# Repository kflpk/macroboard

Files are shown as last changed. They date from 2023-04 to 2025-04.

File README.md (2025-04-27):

macroboard

# Macroboard

Simple ortholinear 4x4 macro keyboard with rotary encoder.

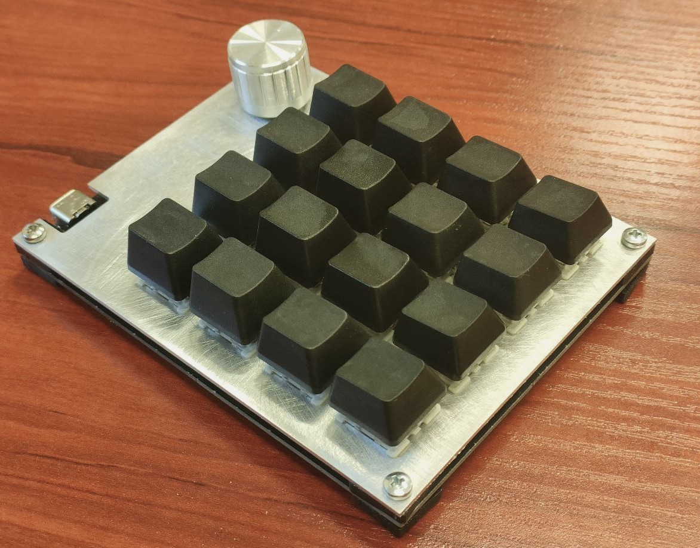
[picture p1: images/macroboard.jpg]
macroboard


## Schematics

The schematics and PCB were created using KiCAD 7. The microcontroller used is an STM32F103C6T6.

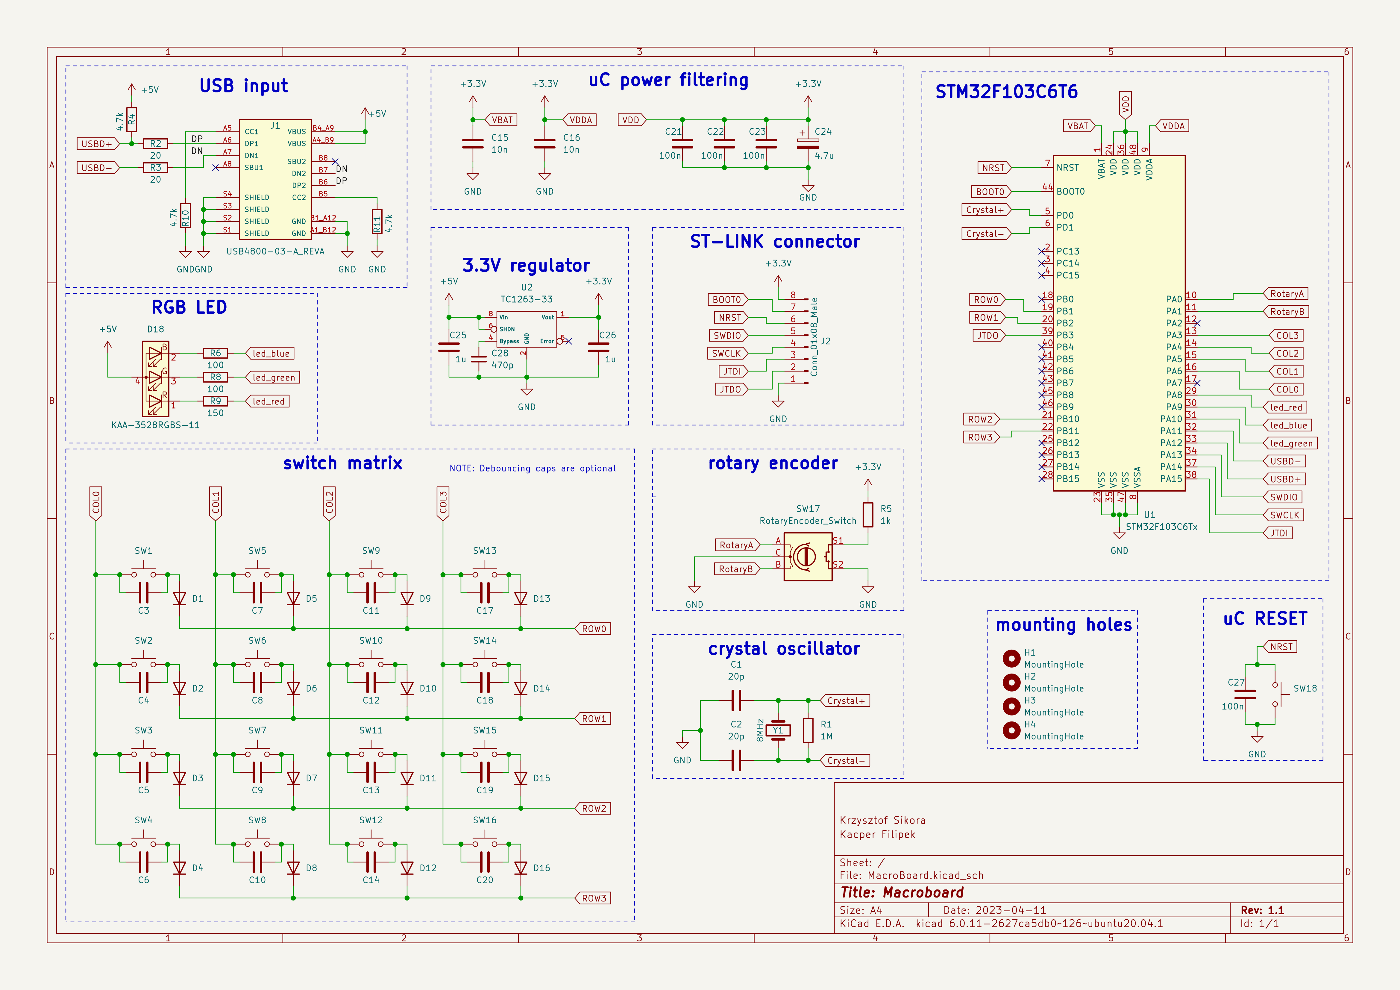
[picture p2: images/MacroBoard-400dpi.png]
schematic


## PCB
Front | Back
:-------------------------:|:-------------------------:
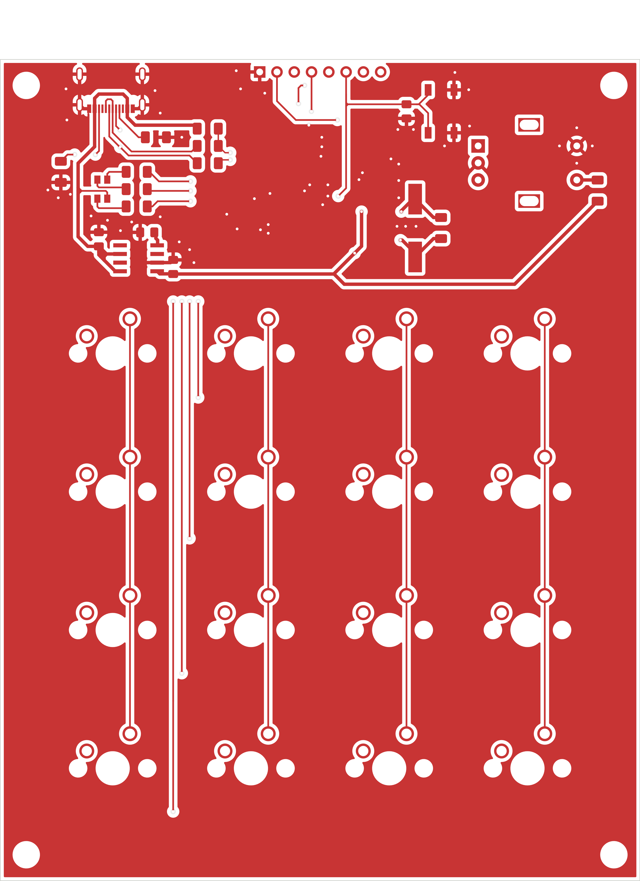
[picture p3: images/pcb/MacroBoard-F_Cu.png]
Front layer
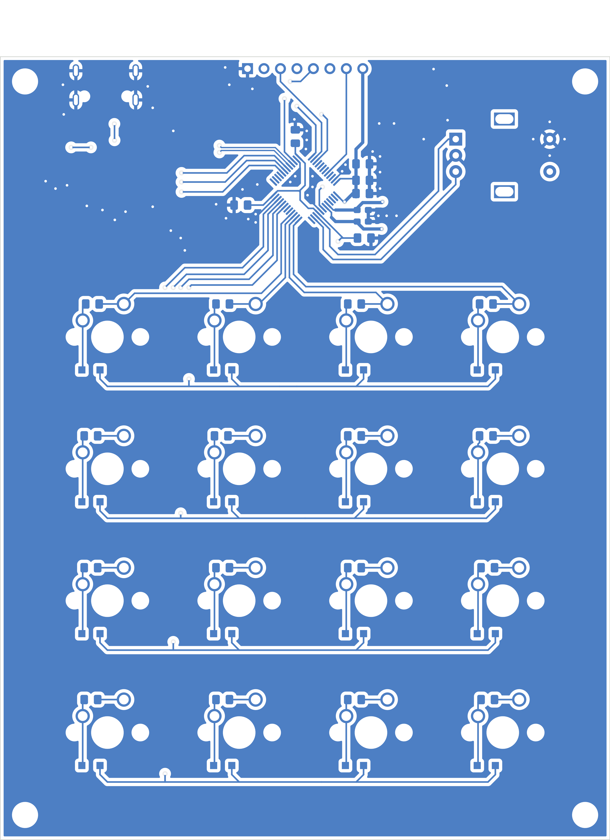
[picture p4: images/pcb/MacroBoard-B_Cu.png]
Back layer
 | 

## Mechanical parts

Mechanical design was done using Fusion 360. The front plate is a 1.5 mm thick aluminium plate, cut using a 3-axis CNC machine.
Standoffs for the board and plate were 3D printed with TPU.

You can find all the necessary files in the "mechanical" folder.

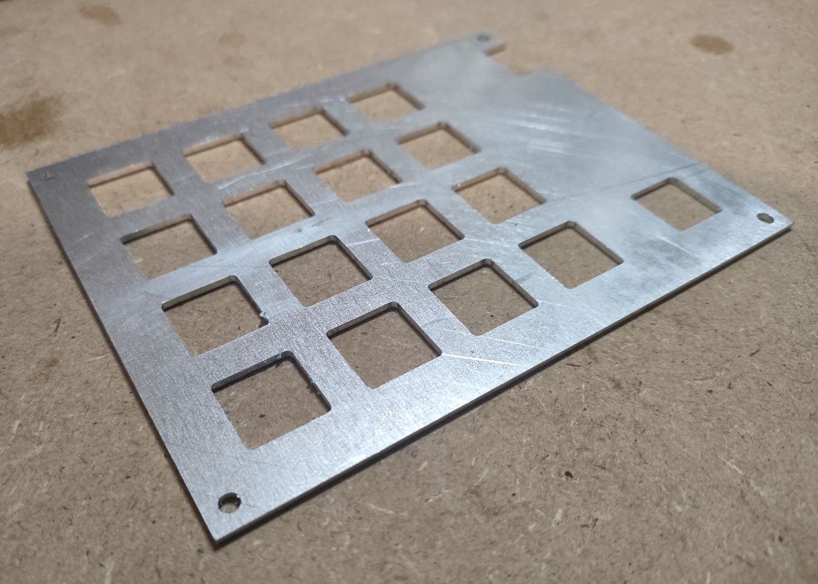
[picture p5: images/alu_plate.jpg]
alu_plate


## Dependencies
```
arm-none-eabi-binutils
arm-none-eabi-gcc
arm-none-eabi-newlib
```

## Authors
* Kacper Filipek
* Krzysztof Sikora

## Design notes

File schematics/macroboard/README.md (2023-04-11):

This folder contains the following Kicad files:
  - schematic
  - PCB design

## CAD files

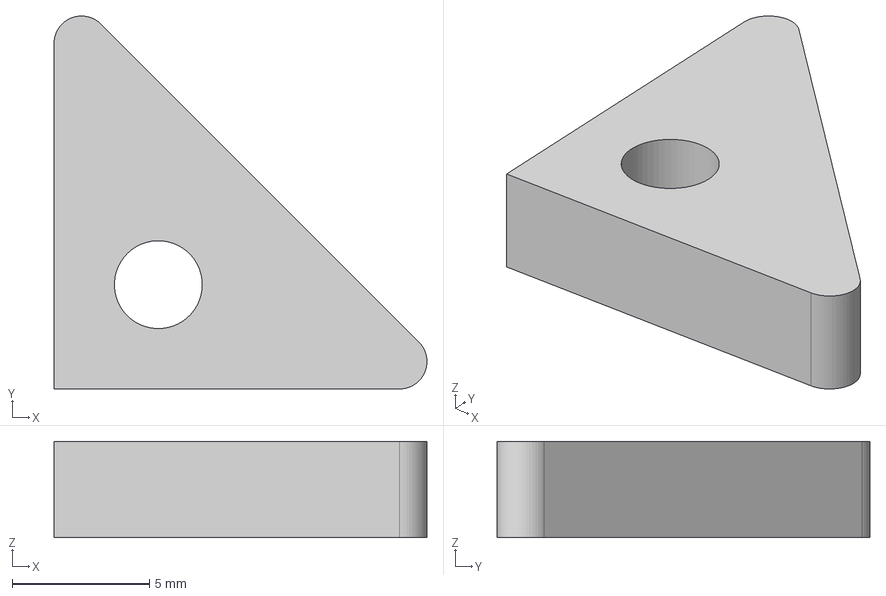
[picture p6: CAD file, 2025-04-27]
mechanical/M3 spacer.step
13.6 x 13.6 x 3.50 mm

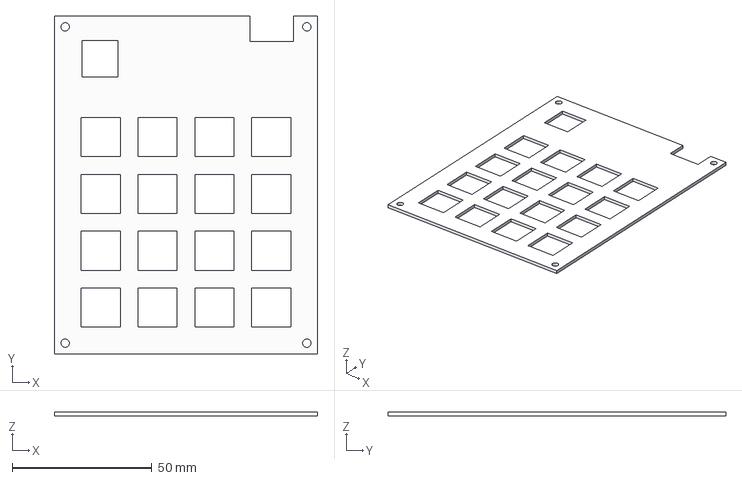
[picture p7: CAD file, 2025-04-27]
mechanical/Macroboard plate.step
94.0 x 120.7 x 1.50 mm

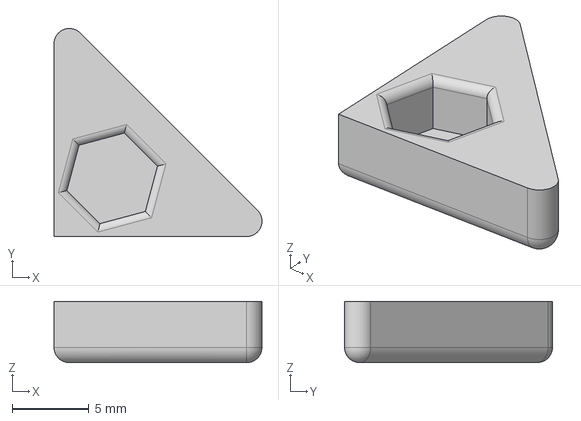
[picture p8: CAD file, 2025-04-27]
mechanical/M3 nut covers.step
13.6 x 13.6 x 4.00 mm

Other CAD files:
mechanical/M3 nut covers.f3d
mechanical/M3 spacer.f3d

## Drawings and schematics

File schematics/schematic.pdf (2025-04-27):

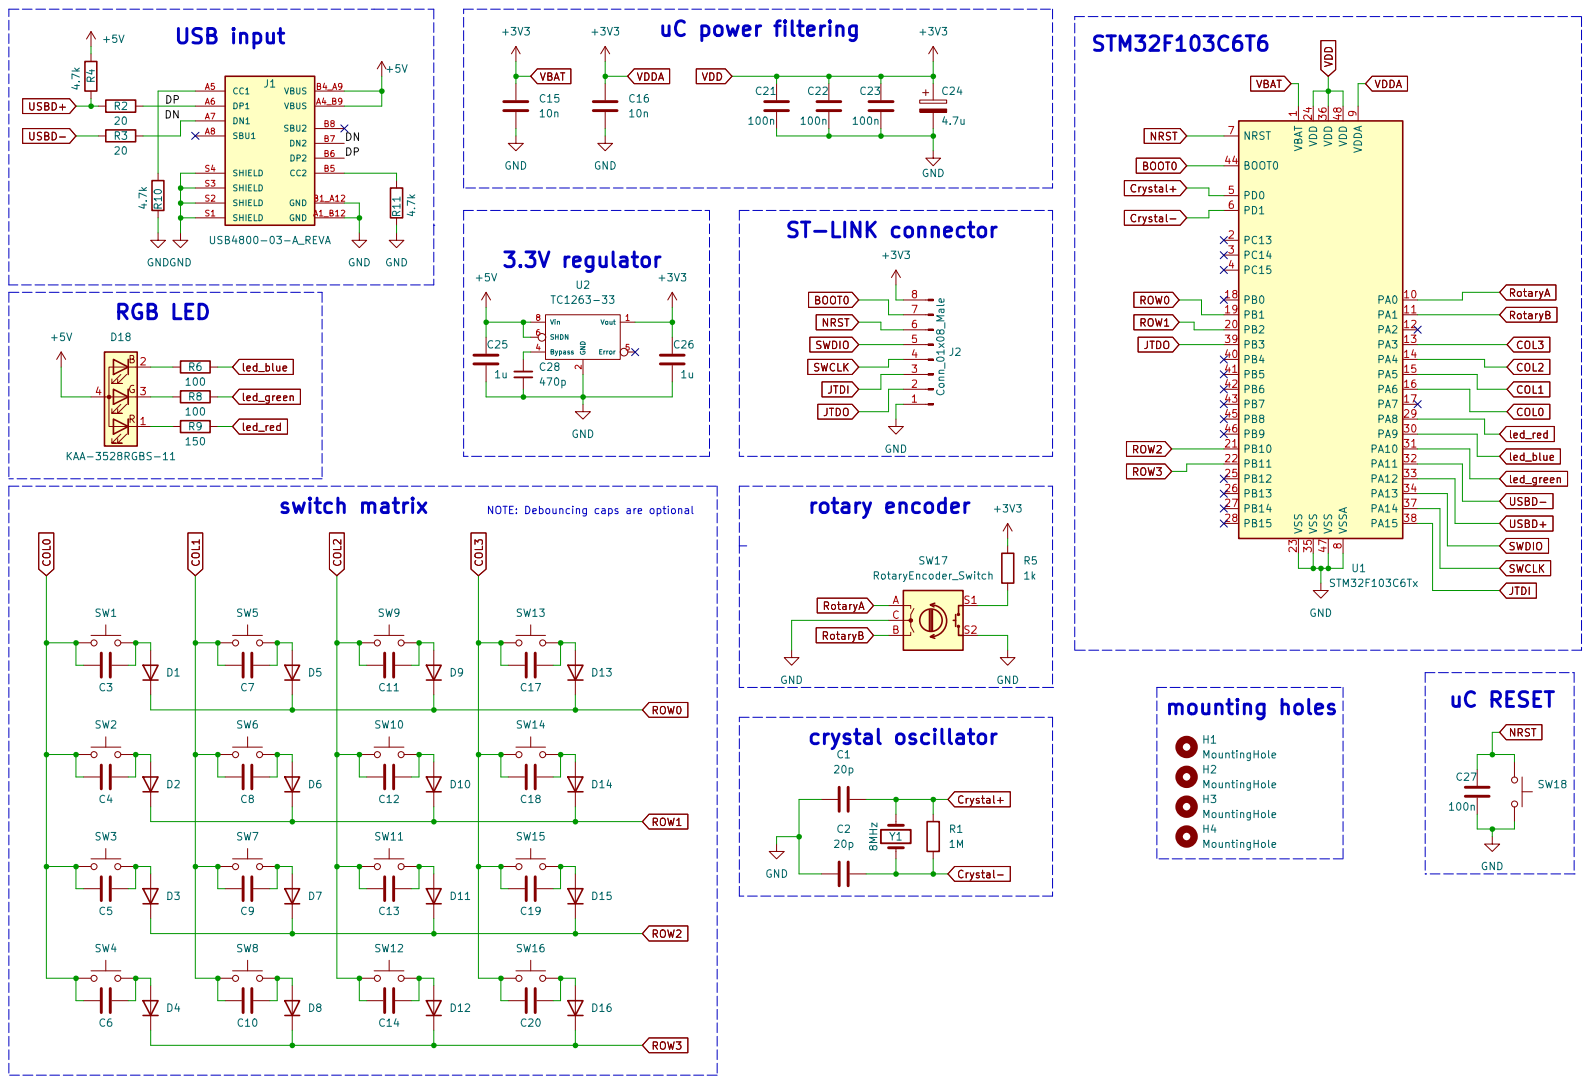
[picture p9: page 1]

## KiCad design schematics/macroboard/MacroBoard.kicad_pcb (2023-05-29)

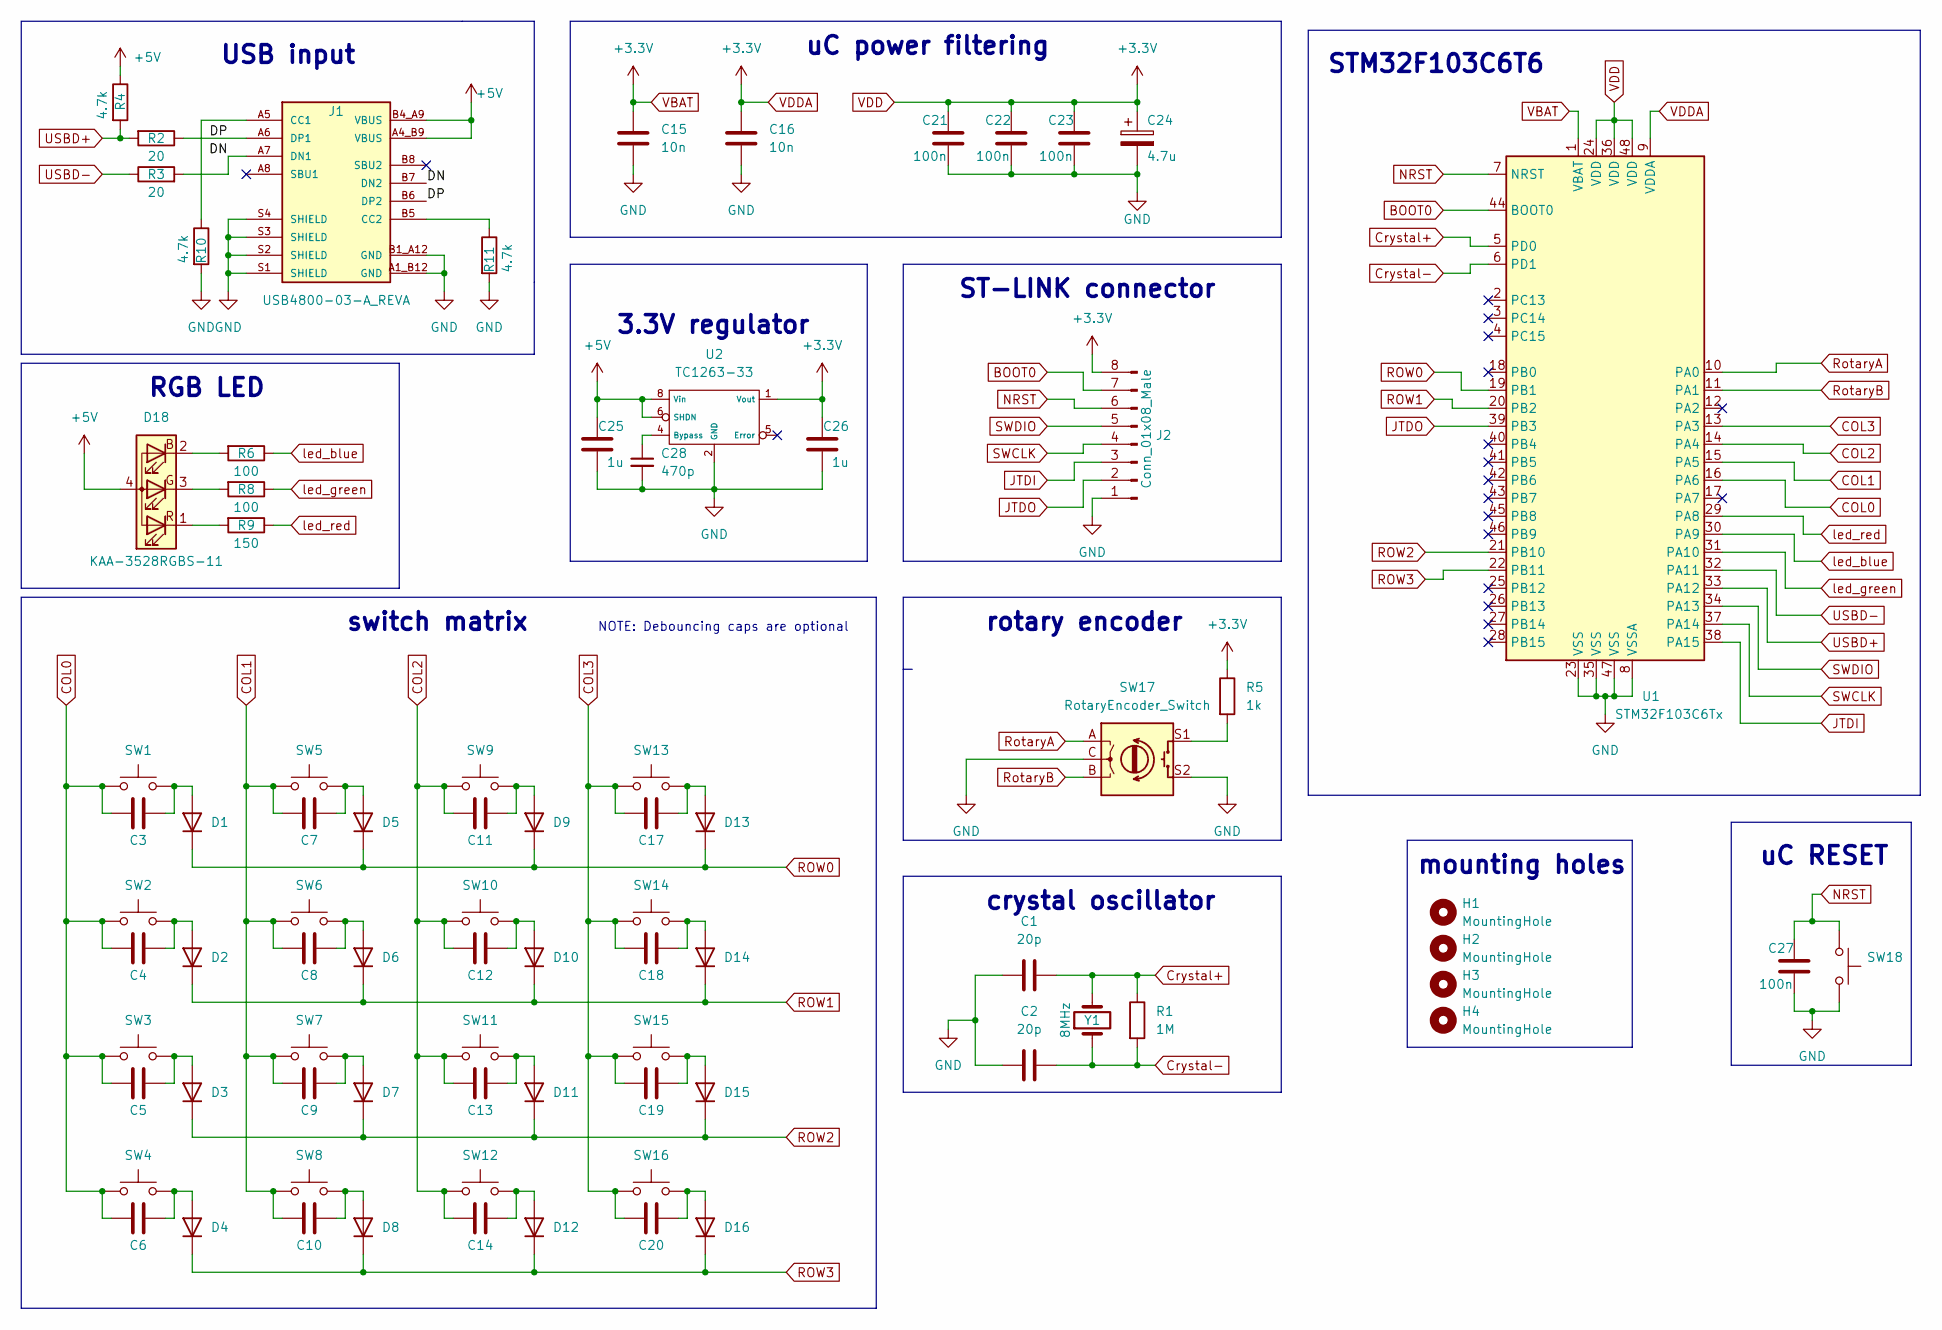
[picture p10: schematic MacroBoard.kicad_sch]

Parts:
C1, C2: 20p; C_0603_1608Metric_Pad1.08x0.95mm_HandSolder
C3, C4, C5, C6, C7, C8, C9, C10, C11, C12, C13, C14, C17, C18, C19, C20: C; C_0805_2012Metric_Pad1.18x1.45mm_HandSolder
C15, C16: 10n; C_0805_2012Metric_Pad1.18x1.45mm_HandSolder
C21, C22, C23, C27: 100n; C_0805_2012Metric_Pad1.18x1.45mm_HandSolder
C24: 4.7u; C_0805_2012Metric_Pad1.18x1.45mm_HandSolder
C25, C26: 1u; C_0805_2012Metric_Pad1.18x1.45mm_HandSolder
C28: 470p; C_0805_2012Metric_Pad1.18x1.45mm_HandSolder
D1, D2, D3, D4, D5, D6, D7, D8, D9, D10, D11, D12, D13, D14, D15, D16: D; D_SOD-123F
D18: KAA-3528RGBS-11; LED_AAA3528LSEKJ3ZGKQBKS
H1, H2, H3, H4: MountingHole; MountingHole_3mm
J1: USB4800-03-A_REVA; GCT_USB4800-03-A_REVA; PARTREV A
J2: Conn_01x08_Male; PinHeader_1x08_P2.54mm_Horizontal
R1: 1M; R_1206_3216Metric_Pad1.30x1.75mm_HandSolder
R2, R3: 20; R_1206_3216Metric_Pad1.30x1.75mm_HandSolder
R4, R10, R11: 4.7k; R_1206_3216Metric_Pad1.30x1.75mm_HandSolder
R5: 1k; R_1206_3216Metric_Pad1.30x1.75mm_HandSolder
R6, R8: 100; R_1206_3216Metric_Pad1.30x1.75mm_HandSolder
R9: 150; R_1206_3216Metric_Pad1.30x1.75mm_HandSolder
SW1, SW2, SW3, SW4, SW5, SW6, SW7, SW8, SW9, SW10, SW11, SW12, SW13, SW14, SW15, SW16: SW_Push; SW_Cherry_MX_1.00u_PCB
SW17: RotaryEncoder_Switch; RotaryEncoder_Alps_EC11E-Switch_Vertical_H20mm
SW18: SW_Push; SW_SPST_TL3342
U1: STM32F103C6Tx; LQFP-48_7x7mm_P0.5mm
U2: TC1263-33; PowerIntegrations_SO-8
Y1: 8MHz; Crystal_SMD_HC49-SD

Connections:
+5V: C25.1, D18.4 (A), J1.A4_B9 (VBUS), J1.B4_A9 (VBUS), R4.1, U2.6 (SHDN), U2.8 (Vin)
/DN: J1.A7 (DN1), J1.B7 (DN2), R3.2
/DP: J1.A6 (DP1), J1.B6 (DP2), R2.1
BOOT0: J2.7, U1.44 (BOOT0)
COL0: C3.1, C4.1, C5.1, C6.1, SW1.1, SW2.1, SW3.1, SW4.1, U1.16 (PA6)
COL1: C7.1, C8.1, C9.1, C10.1, SW5.1, SW6.1, SW7.1, SW8.1, U1.15 (PA5)
COL2: C11.1, C12.1, C13.1, C14.1, SW9.1, SW10.1, SW11.1, SW12.1, U1.14 (PA4)
COL3: C17.1, C18.1, C19.1, C20.1, SW13.1, SW14.1, SW15.1, SW16.1, U1.13 (PA3)
Crystal+: C1.2, R1.1, U1.5 (PD0), Y1.2
Crystal-: C2.2, R1.2, U1.6 (PD1), Y1.1
GND: C1.1, C2.1, C15.2, C16.2, C21.2, C22.2, C23.2, C24.2, C25.2, C26.2, C27.1, C28.2, J1.A1_B12 (GND), J1.B1_A12 (GND), J1.S1 (SHIELD), J1.S2 (SHIELD), J1.S3 (SHIELD), J1.S4 (SHIELD), J2.1, R10.2, R11.2, SW17.C, SW17.S2, SW18.2, U1.8 (VSSA), U1.23 (VSS), U1.35 (VSS), U1.47 (VSS), U2.2 (GND)
JTDI: J2.3, U1.38 (PA15)
JTDO: J2.2, U1.39 (PB3)
NRST: C27.2, J2.6, SW18.1, U1.7 (NRST)
unnamed: C3.2, D1.2 (A), SW1.2
unnamed: C4.2, D2.2 (A), SW2.2
unnamed: C5.2, D3.2 (A), SW3.2
unnamed: C6.2, D4.2 (A), SW4.2
unnamed: C7.2, D5.2 (A), SW5.2
unnamed: C8.2, D6.2 (A), SW6.2
unnamed: C9.2, D7.2 (A), SW7.2
unnamed: C10.2, D8.2 (A), SW8.2
unnamed: C11.2, D9.2 (A), SW9.2
unnamed: C12.2, D10.2 (A), SW10.2
unnamed: C13.2, D11.2 (A), SW11.2
unnamed: C14.2, D12.2 (A), SW12.2
unnamed: C17.2, D13.2 (A), SW13.2
unnamed: C18.2, D14.2 (A), SW14.2
unnamed: C19.2, D15.2 (A), SW15.2
unnamed: C20.2, D16.2 (A), SW16.2
unnamed: C28.1, U2.4 (Bypass)
unnamed: D18.1 (RK), R9.2
unnamed: D18.2 (BK), R6.2
unnamed: D18.3 (GK), R8.2
unnamed: J1.A5 (CC1), R10.1
unnamed: J1.B5 (CC2), R11.1
unnamed: R5.2, SW17.S1
ROW0: D1.1 (K), D5.1 (K), D9.1 (K), D13.1 (K), U1.19 (PB1)
ROW1: D2.1 (K), D6.1 (K), D10.1 (K), D14.1 (K), U1.20 (PB2)
ROW2: D3.1 (K), D7.1 (K), D11.1 (K), D15.1 (K), U1.21 (PB10)
ROW3: D4.1 (K), D8.1 (K), D12.1 (K), D16.1 (K), U1.22 (PB11)
RotaryA: SW17.A, U1.10 (PA0)
RotaryB: SW17.B, U1.11 (PA1)
SWCLK: J2.4, U1.37 (PA14)
SWDIO: J2.5, U1.34 (PA13)
USBD+: R2.2, R4.2, U1.33 (PA12)
USBD-: R3.1, U1.32 (PA11)
VBAT: C15.1, C16.1, C21.1, C22.1, C23.1, C24.1, C26.1, J2.8, R5.1, U1.1 (VBAT), U1.9 (VDDA), U1.24 (VDD), U1.36 (VDD), U1.48 (VDD), U2.1 (Vout)
led_blue: R6.1, U1.30 (PA9)
led_green: R8.1, U1.31 (PA10)
led_red: R9.1, U1.29 (PA8)

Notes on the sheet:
STM32F103C6T6
rotary encoder
uC RESET
switch matrix
USB input
mounting holes
3.3V regulator
RGB LED
ST-LINK connector
crystal oscillator
uC power filtering
NOTE: Debouncing caps are optional

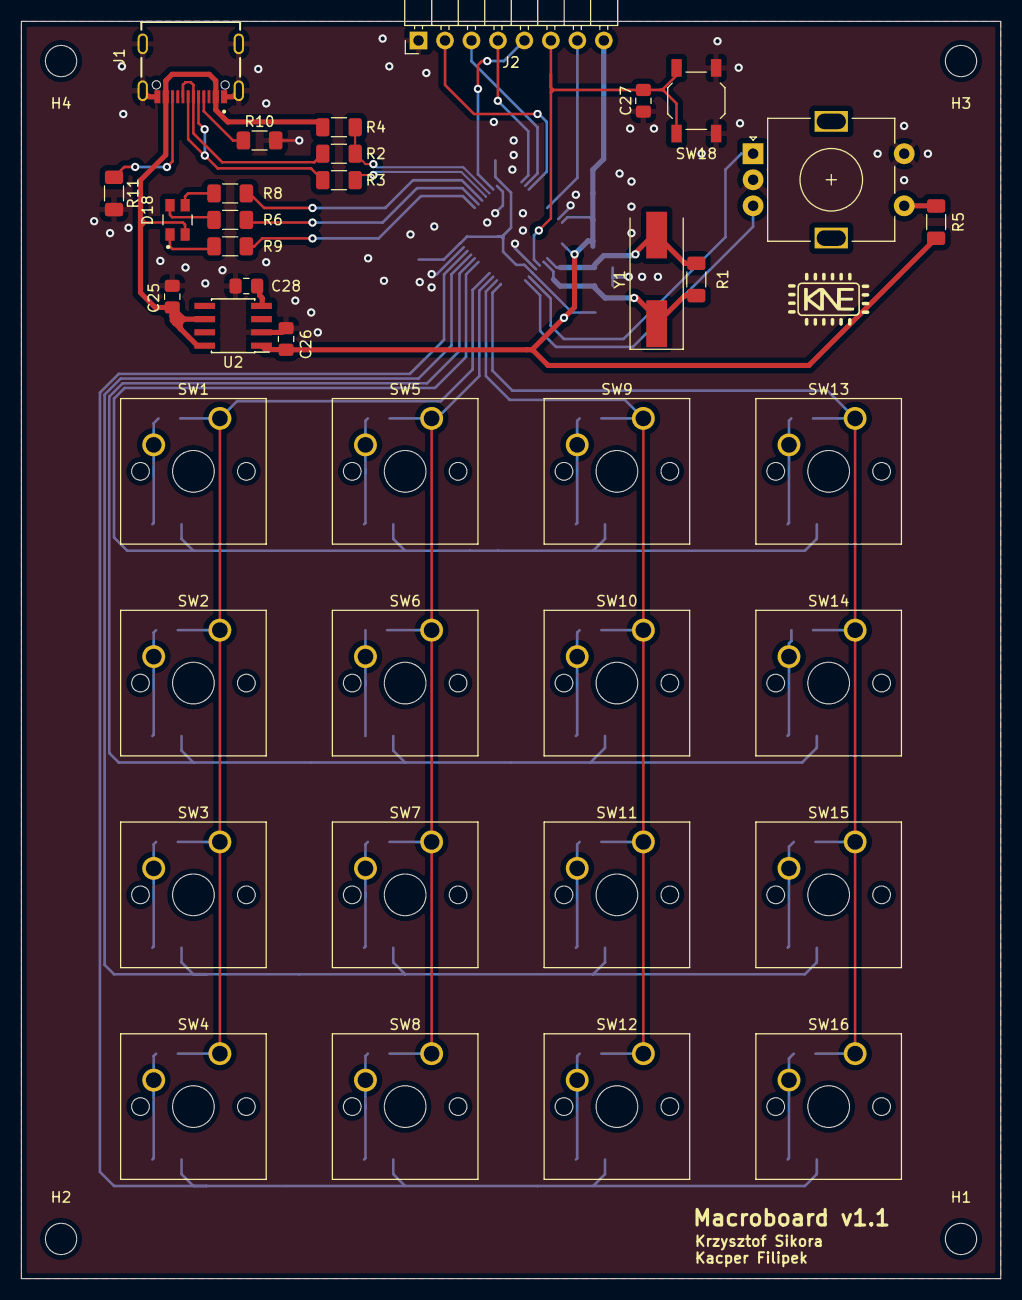
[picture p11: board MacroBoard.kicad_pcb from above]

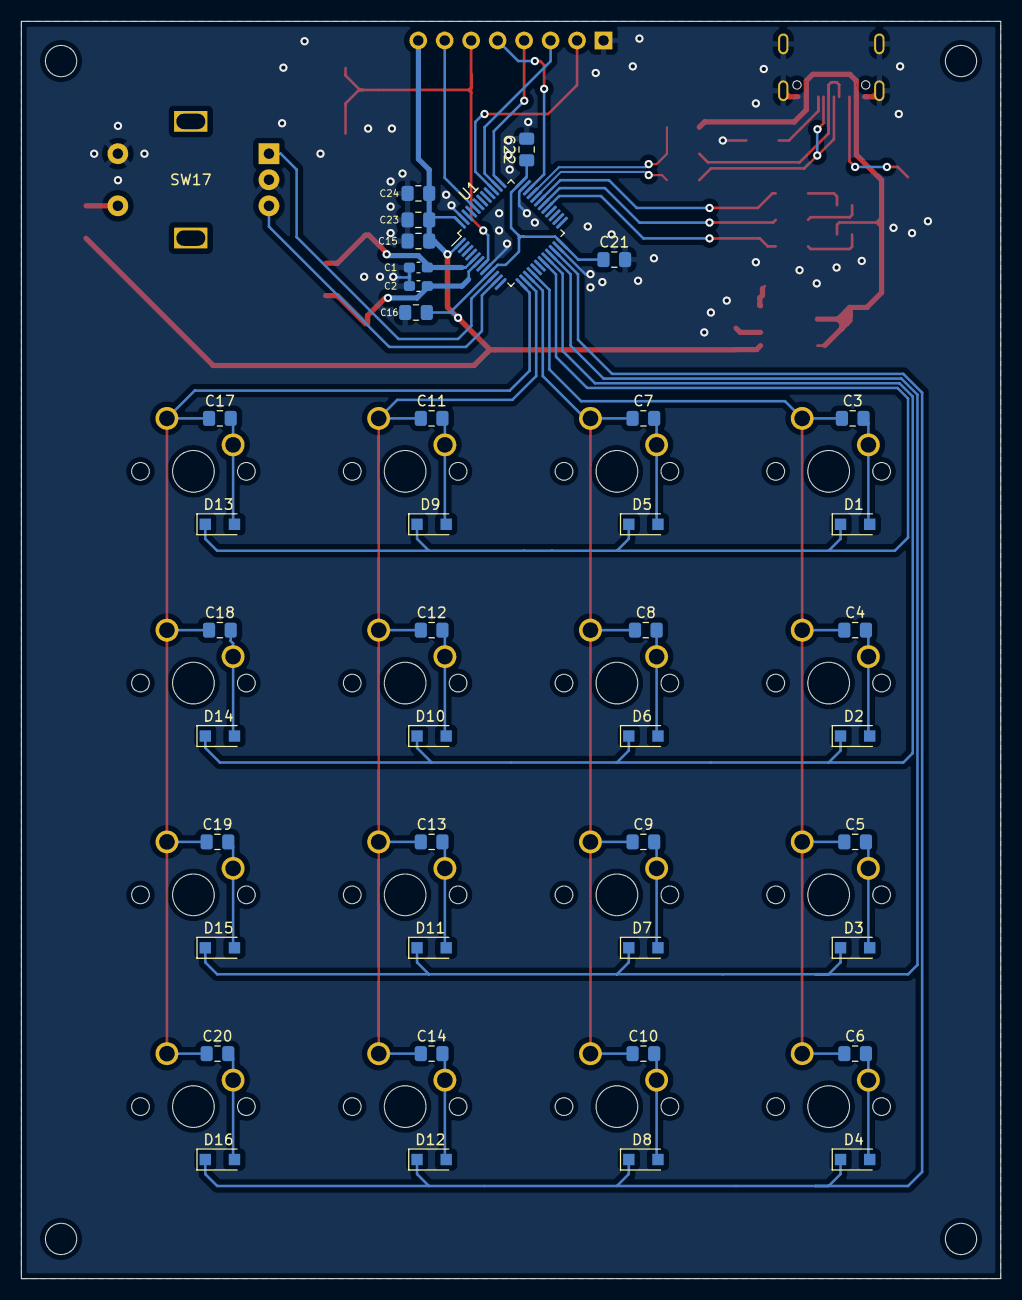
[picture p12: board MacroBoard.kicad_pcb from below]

Board: 2 copper layers, 94.0 x 120.6 mm, 82 parts (41 on the bottom side), 51 nets.

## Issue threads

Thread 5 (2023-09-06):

Remove the LED

kflpk, 2023-09-06:
remove the LED from the PCB, cause QMK doesn't seem to support controlling LEDs by PWM

Closed 2025-04-25.

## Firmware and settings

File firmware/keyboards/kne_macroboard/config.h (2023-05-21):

// This file was adapted from ck4x4 keyboard from qmk_firmware github repository

/*
Copyright 2015 Jun Wako <wakojun@gmail.com>
Copyright 2023 Kacper Filipek <filipek.kacper@gmail.com>

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
You should have received a copy of the GNU General Public License
along with this program.  If not, see <http://www.gnu.org/licenses/>.
*/

#pragma once

#define MATRIX_COL_PINS { A6, A5, A4, A3 }
#define MATRIX_ROW_PINS { B1, B2, B10, B11 }
#define DIODE_DIRECTION COL2ROW
#define ENCODERS_PAD_B { A0 }
#define ENCODERS_PAD_A { A1 }
#define ENCODER_RESOLUTION 4

//LEDS A6, RGB B15

/* Mechanical locking support. Use KC_LCAP, KC_LNUM or KC_LSCR instead in keymap */
#define LOCKING_SUPPORT_ENABLE
/* Locking resynchronize hack */
#define LOCKING_RESYNC_ENABLE
#define FEE_MCU_FLASH_SIZE 32
#define FEE_PAGE_COUNT 2
#define FEE_PAGE_SIZE 1024

/*
 * Feature disable options
 *  These options are also useful to firmware size reduction.
 */

/* disable debug print */
//#define NO_DEBUG

/* disable print */
//#define NO_PRINT

/* disable action features */
//#define NO_ACTION_LAYER
//#define NO_ACTION_TAPPING
//#define NO_ACTION_ONESHOT

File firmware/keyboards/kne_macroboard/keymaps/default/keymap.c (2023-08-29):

// Copyright 2023 QMK
// SPDX-License-Identifier: GPL-2.0-or-later

#include QMK_KEYBOARD_H

enum custom_keycodes {
    MACRO_SW1 = SAFE_RANGE,
};

bool process_record_user(uint16_t keycode, keyrecord_t* record) {
    switch(keycode) {
        case MACRO_SW1:
            if(record->event.pressed) {
                SEND_STRING("email@example.com");
            }
            return false;
        break;
    }
    return true;
}

const uint16_t PROGMEM keymaps[][MATRIX_ROWS][MATRIX_COLS] = {
    [0] = LAYOUT_ortho_4x4(
        KC_A,   KC_B,  KC_C, KC_D, KC_E, KC_F, KC_G, KC_H, KC_I, KC_J, KC_K, KC_L, KC_M, KC_N, KC_O, KC_P
    )
};

#if defined(ENCODER_MAP_ENABLE)
const uint16_t PROGMEM encoder_map[][NUM_ENCODERS][1] = {
    [0] =   { ENCODER_CCW_CW(KC_MS_WH_UP, KC_MS_WH_DOWN) },
};
#endif

bool encoder_update_user(uint8_t index, bool clockwise) {
    if (index == 0) { /* First encoder */
        if (clockwise) {
            tap_code_delay(KC_VOLU, 10);
        } else {
            tap_code_delay(KC_VOLD, 10);
        }
    }
    return false;
}

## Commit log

2023-04-11 final pcb updates
    [MacroBoard.kicad_pcb, MacroBoard.kicad_sch]
2023-04-11 minor cleanup on schematic, hided value labels on switches on keyboard matrix for better readability
    [MacroBoard.kicad_pcb, MacroBoard.kicad_sch]
2023-05-10 some automatic changes in kicad files
2023-05-29 schematic: moved row connections to the side of the pcb
    [MacroBoard.kicad_pcb]
2025-04-25 Added mechanical parts and updated README
    [M3 nut covers.f3d, M3 nut covers.step, M3 spacer.f3d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]

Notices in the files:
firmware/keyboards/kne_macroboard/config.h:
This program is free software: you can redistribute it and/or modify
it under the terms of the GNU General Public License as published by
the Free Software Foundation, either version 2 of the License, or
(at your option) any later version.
